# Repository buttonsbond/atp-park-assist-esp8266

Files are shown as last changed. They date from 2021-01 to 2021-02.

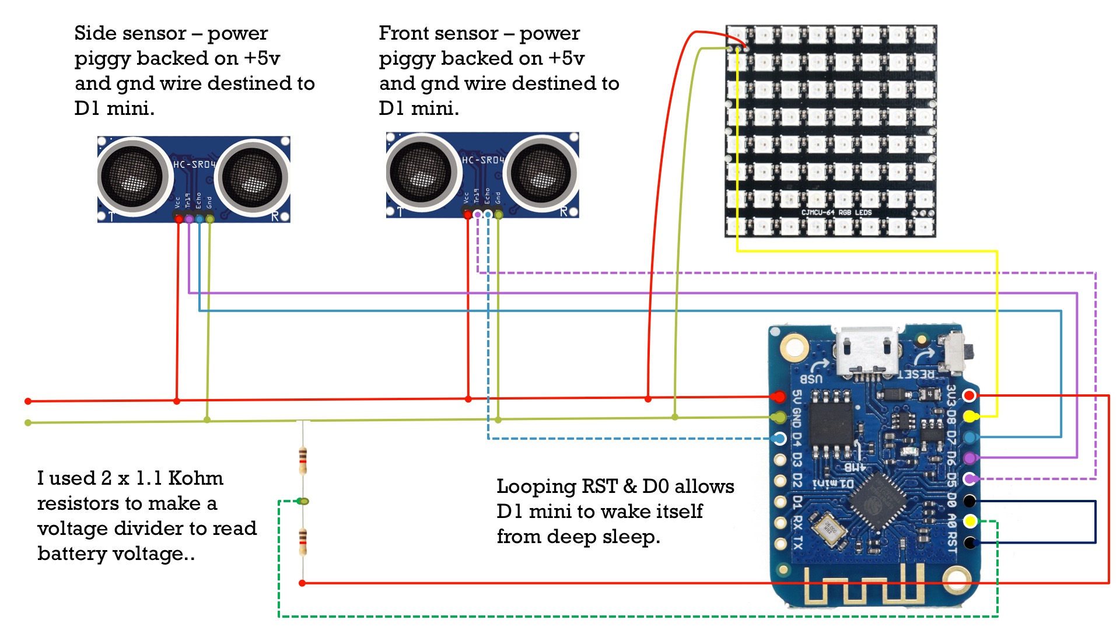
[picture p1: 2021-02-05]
Slide2.jpeg

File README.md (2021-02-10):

# atp-park-assist-esp8266
Parking assist using 2 ultrasonic sensors, 8x8 RGB pixel and d1 mini clone. Optionally you can connect a 4 panel LCD screen to help with debugging/calibrating when the equipment is in situ.
===========================
Just had an automatic rolling door fitted to the drive. Parking is a bit tight due to the car port we have, the middle posts get in the way of the drivers/passenger door opening. It is possible, if you park just right to get in and out of at least one of those doors. A parking sensor to help would be just the job, one to judge if the car is far enough forward, and another at the side to judge if over to the right enough. This project utilises 2 ultrasonic 5v sensors (HC-SR04), a D1 Mini clone (4Mb version), and an 8x8 RGB pixel panel.

most of default settings can be changed in settings.h

Features
========

1. Calibrate either sensor for its minimum distance by placing your fingers over each sensor. A reading of over 1000 will result triggering the calibrate routine.
2. Advancing arrow shown in green, yellow then red (on the 8x8 RGB) for the front sensor. When red, it's time to stop!
3. Left and right hand side of the RGB shown in green, yellow then blue for the side sensor. Blue means your car is far enough over.
4. When no change in forward movement is detected - ie. reading doesn't change much, the micro-controller will enter deepsleep (whether this helps save the battery only time will tell)
5. Various variables saved to RTC when the unit sleeps, and reloaded when it wakes up - a quick front reading is taken and if there still isn't any change the controller enters deepsleep again.
6. OTA updating is possible - it may fail if you happen to try and upload during a sleep operation.
7. An LCD display can be connected to monitor the units operation (recommended only for debugging/setup) - comment out in the code to disable support.
8. Voltage can be monitored if enabled - not fully implemented to do anything with yet but ideally for a low battery warning.
9. MQQT implemented to send front and side readings, f&s limits (after a calibration), time (periodically), whether parked or not (1 or 0), voltage level (see notes further down). 

3D Models
=========
The folder final-models contains some STL files of the enclosures I created and used - the originals are in Tinkercad. 
* remixed-from-tinkercad-user-weselle - in this folder 2 x STL files for the ultrasonic sensor enclosure. Bear in mind that I bent the pins almost fully back on themselves rather than sticking out of the top/bottom - if you still want the pins sticking out the bottom/top then checkout weselle on Tinkercad.
* boxslot.stl - the main box with a thin lip in the bottom to stop the LED grid falling out (you can optionally print insert.stl in white to create a diffuser to go in first ahead of the LED grid.
* mountsall.stl - this is an square 1mm insert that goes in on top of the LED grid, it has posts for mounting D1 mini (my version has holes for the posts to go through), posts for mounting standard DC buck converter, and a holder for 12V 23A battery, the battery found commonly in cheap doorbell push button units.
-- note, that original idea of using a buck converter with a 12V battery wasn't sound - novice that I am, didn't know that the converter would run the battery down even when nothing connected, so plan b is to add a battery shield to the D1 mini and a LIPO battery of 1200mah. I am hoping that with the deep sleep used in the programming that the battery will last a while without recharging. I will expose the usb charging port to allow recharging from something like a power bank.
* plug.stl - this is the mount I made to slot into the metal aluminium tubing I mount the main unit on, it slides into place (quite tightly)
* insert.stl - print this in white PLA for a diffuser (optional) - FILE NOT YET ADDED
* lid.stl - lid for the main box - FILE NOT YET ADDED

You'll need 2 each of the ultrasonic sensor models.

TO DO
=====

1. Low battery warning (see note under wiring up!)
2. Try and further combat spurious readings from the sensors (tried a few libraries) - if anyone can offer a solution that'd be appreciated. I've built in various checks to try and combat this. I read somewhere that the Newping library might be an option which I might try once I've got the power issues sorted.
3. When red, instead of an advancing arrow maybe just flashing red square.

I recommend that once you configure for your car that you hard code those distances in settings.h

Wiring up
=========
I've included a couple of exported Powerpoint slides to show how I wired up. However, it's not quite right - I need some help on this one. Basically I have a small solar panel repurposed from a solar outside light from LIDL - it gives out up to about 5 volts when in direct sun. No idea what the charge current is. It's enough to light the red LED on the battery shield but I don't think it is enough for charging.
I added in the power board so that the battery shield output should give 5 volts for as long as it can (this of course makes my voltage measurement incorrect, and since I haven't put the battery shield in the same enclosure as the D1 mini unless I run a separate wire for the 3v output of the battery shield module to the d1 mini I won't be able to get a reading from the batteries - maybe I don't need the voltage regulator if I can get the solar charging working). The battery drains after about 8 or 9 hours (2000mah 3.7v lion battery) at the moment.
I'm not an electronics expert by any stretch of the imagination so if someone can let me know what the setup should be - comment away!

Libraries needed/used
=====================

Thanks to the respective authors of these libraries, and apologies if I missed any

* https://github.com/bbkbarbar/Arduino-HC-SR04-library
* https://github.com/highno/rtcvars

Caveat
I recommend you use the same pins as I did. I had an issue with one of the (now) unused pins when the LCD panel was also in use in that one of the sensors stopped working. Not sure why but changing it got over that.

Say hi
If you like my project, please send me a photo and say hi. If you have any improvements, be my guest and remember to share back!

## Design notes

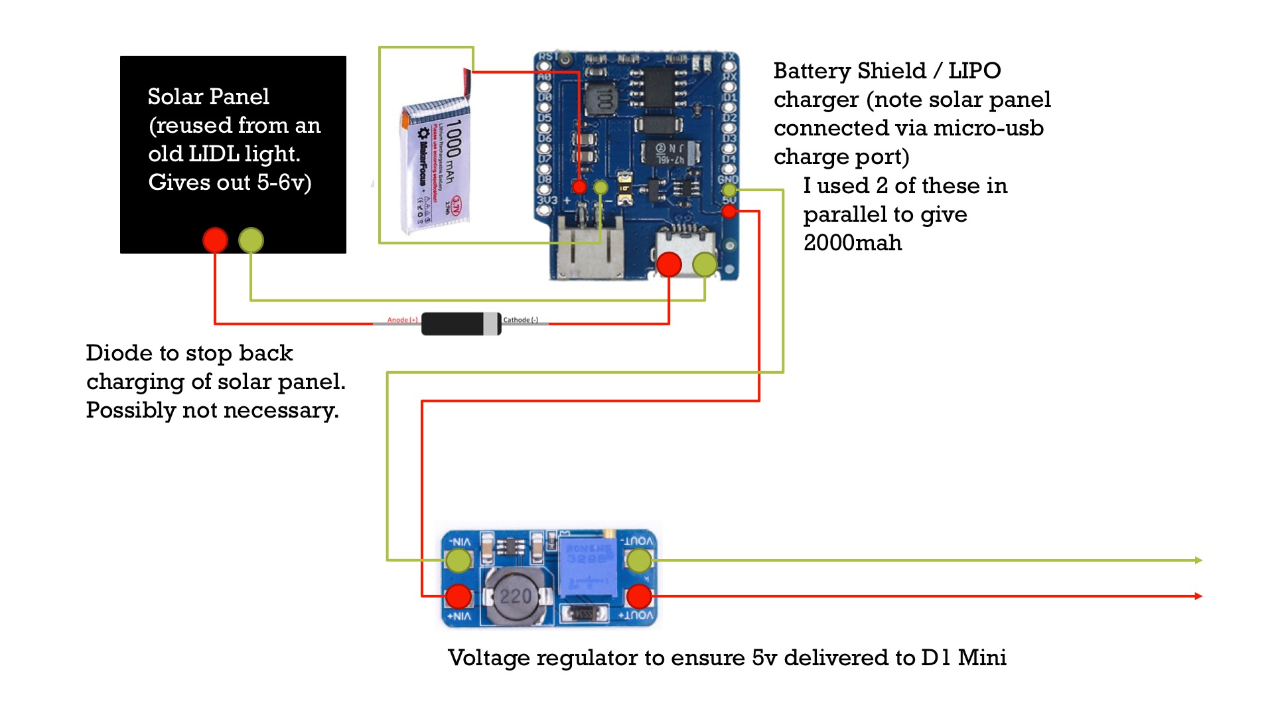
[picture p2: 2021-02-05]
Slide1.jpeg

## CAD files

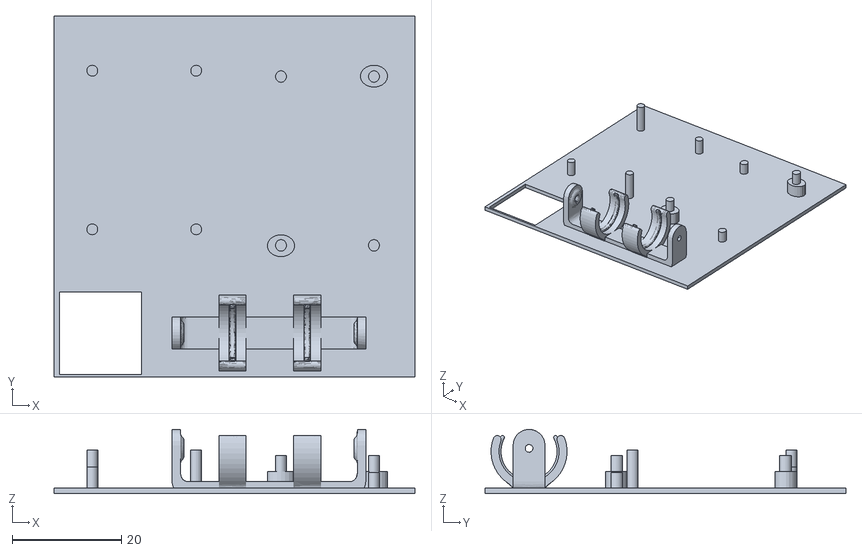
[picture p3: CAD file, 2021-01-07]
final-models/mountsall.stl
66.0 x 66.0 x 11.7

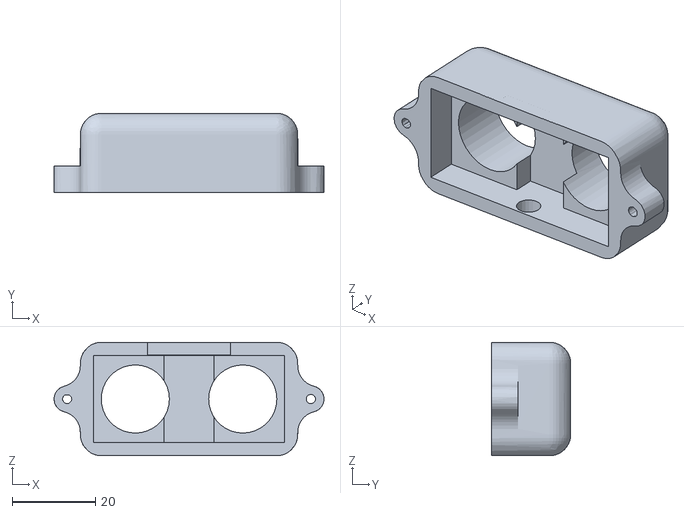
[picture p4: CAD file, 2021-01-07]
final-models/remixed-from-tinkercad-user-weselle/hcsr04case.stl
65.0 x 19.1 x 27.3

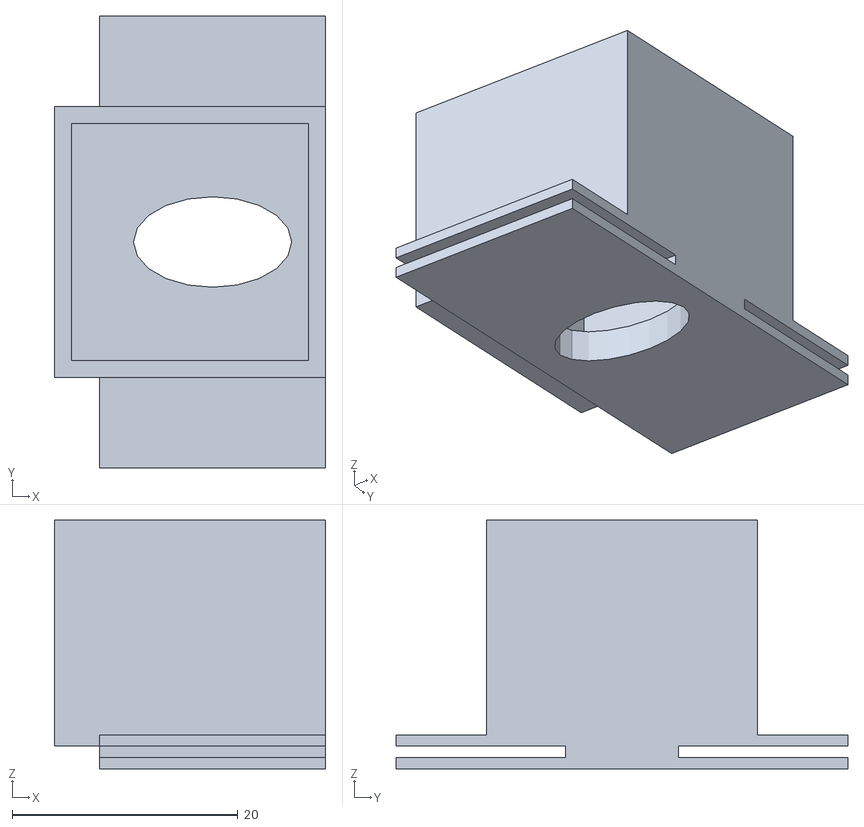
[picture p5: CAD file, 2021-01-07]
final-models/plug.stl
24.0 x 40.0 x 22.0

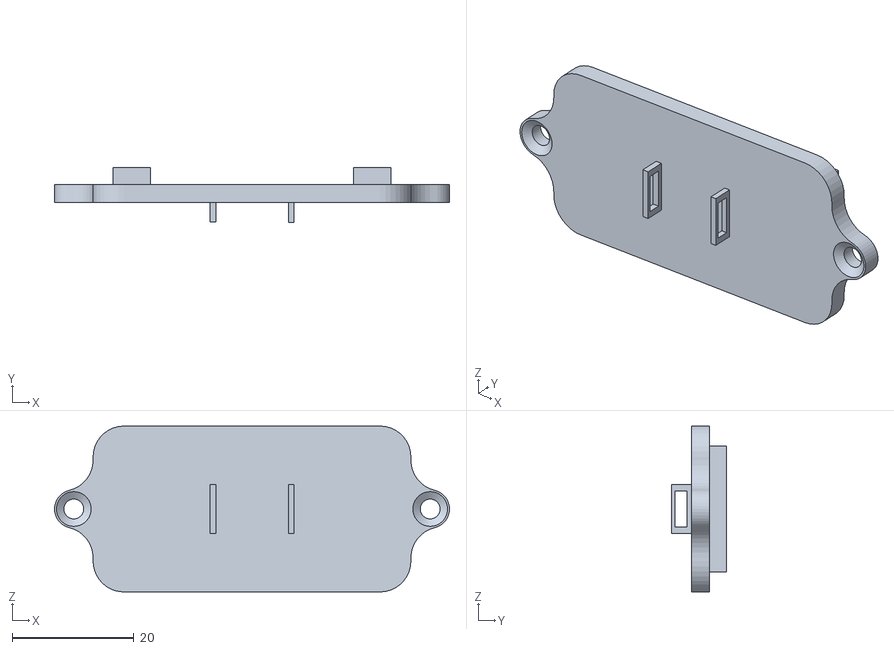
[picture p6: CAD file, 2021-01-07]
final-models/remixed-from-tinkercad-user-weselle/hcsr04lid.stl
65.0 x 9.09 x 27.3

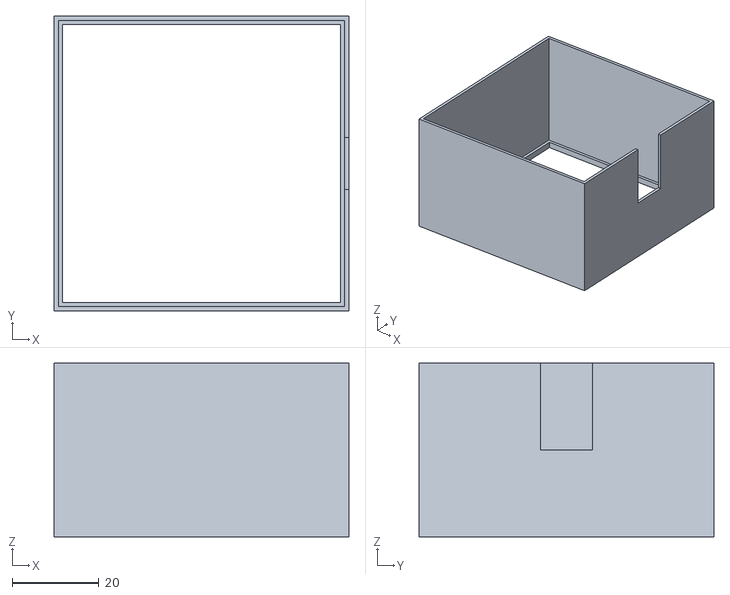
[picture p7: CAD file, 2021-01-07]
final-models/boxslot.stl
68.0 x 68.0 x 40.0

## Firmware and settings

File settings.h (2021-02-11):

struct pcolour {int r; int g; int b;} __attribute__((packed));
typedef struct pcolour PC;
PC rgb;

char* host = "parking";   // Friendly hostname (todo: generate a unique hostname so don't have to set on per board basis
String h = "parking";

// Replace with your network credentials
const char* ssid = "Telfy_3316";
const char* password = "jonesxa1";

// Settings for the HC-SR04 sensors
//
// setup for ultrasonic detector 1 - this will be use to measure distance to front of car
//const int trigPinFront = 
const int trigPinFront = D4; 
const int echoPinFront = D5;
// setup for ultrasonic detector 2 - this will be used to measure distance of side of car to check for correct door opening
const int trigPinSide = D6;
const int echoPinSide = D7;
//
// variables for timings for sound to bounce back and be detected and then to store the distance in
//
long durationFront;
int distanceFront;
long durationSide;
int distanceSide;

// ideally once you know the side and front values for parking your car you should change the values below
// these will then default on power restore
// also measure your distance maxes - front will be from the sensor to your garage door, side will be approx
// the width of your car

int SetDistanceSide = 35; // default distance to passenger door
int SetDistanceFront = 13; // default distance value
int SetDistanceSideMax = 80; // if the distance from the side of the car is more than this, probably no car in the drive!
int SetDistanceFrontMax = 180; // if any more than this then probably no car in drive
int MidFront = (SetDistanceFrontMax - SetDistanceFront) / 2;
int MidSide = (SetDistanceSideMax - SetDistanceSide) / 2;

double dataFront;
double dataSide; 

// D0
//
// apparently if I want to make use of deep sleep, I need to use D0 and RST joined together
// there should be a switch that can be turned on/off on this otherwise you can't do OTA
// or USB upload for that matter.
//
// D1 and D2 (SCL / SDA)
//
// These pins used for LCD panel which I just use for displaying debug messages
//
// comment out if you don't want to send message to an LCD panel.
//#define LCD_DEBUG
// remove comment if you want serial debugging
//#define SERIAL_DEBUG
// comment out if you don't want MQTT reporting
#define ENABLE_MQTT
 #ifdef ENABLE_MQTT
    WiFiClient wClient;
    PubSubClient client(wClient); // was client
  #endif
//
// setup for the FastLED system
//
#define FASTLED_INTERNAL // this disables the pragma messages during compile time
#include <FastLED.h>
FASTLED_USING_NAMESPACE
#define FASTLED_ESP8266_NODEMCU_PIN_ORDER
//define FASTLED_ESP8266_D1_PIN_ORDER
#define DATA_PIN 8   
const int NUM_LEDS = 64; // this is an 8x8 pixel

uint8_t gHue = 100; // rotating "base color" used by many of the patterns

#ifdef LCD_DEBUG
  #define BRIGHTNESS  1 // not sure if this will help with the 5v to power the lcd panel by making LEDs dimm
  int ledbrightness = 1;
#else if
  #define BRIGHTNESS 10
  int ledbrightness = 10;
#endif 
#define FRAMES_PER_SECOND 30

// declare the array of LEDs
CRGB leds[NUM_LEDS];


// OTA updates
#define ENABLE_OTA      // comment out if you don't want OTA updates
int OTAport = 8266;

// monitor battery voltage
// in the circuit I used 2 12k resistors one from the 3.3v rail the other to the ground rail, with a wire
// connecting from middle of those (voltage divider) to the D1 mini A0 analog input
const int VOLTAGE_IN = A0;
double voltage = 0; 

// sleep delays

int StandardSleep = 10; // sleep time when battery ok
double StandardSleepVolt = 3.3; // volts must be higher than this for the shorter sleep period
int LowPowerSleep = 49; // sleep time when battery getting low
int InactiveSleep = 301; // sleep time during inactive hours
int InactiveStart = 1;
int InactiveEnd = 6;
int CurrentSleep = StandardSleep;
int CurrentHour = 12;
int CurrentMin = 0;
char mytime[6] = "12:00";
int successivechecks = 0;

// time settings
const long utcOffsetInSeconds = 3600;

//
// 
int nochange = 0;
int samereading = 0;
int samereadingcounter = 0;
int CalibrateDistance = 1000; // I think the sensor limit is about 4 metres or so  - you might need to fiddle around with this to see what high reading you get when you cover the sensors

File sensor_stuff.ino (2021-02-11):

void GetDistances(void) {
  TestFront();
  topright(); // output for LCD if enabled
  bottomright(); // output for LCD if enabled
  if (nochange==0) {
  TestSide(); // only test side when the whole shebang is up and running - otherwise if its just a wakeup to check, just test the front sensor
  }
}

void TestFront(void) {
  boolean done = false;
  Front();
  FastLED.setBrightness(ledbrightness);
  FastLED.delay(1000/FRAMES_PER_SECOND);

// only do the LEDs if change in reading
if (nochange==0) {
 
 if (distanceFront <= SetDistanceFront) {
    advance('R'); // Side 'STOP'
    debugmessages("FT: STOP  ");
    done = true;
  }
  if ((distanceFront > MidFront) && (!done)) {
    advance('G'); // Front is miles away
    debugmessages("FT: FAR   ");
    done = true;
  }

  if ((distanceFront <= MidFront) && (!done)) {
    advance('Y'); // front is somewhere between half way there and optimal
    debugmessages("FT: NEAR  ");
    done = true;
  }

}

  if ((distanceFront > CalibrateDistance)) {
      // we will check 1 more time after a delay to make sure this really is a calibration request
      debounce('F');
        if (distanceFront > CalibrateDistance) {
            debugmessages("FRONT CALIBRATION");
        calibrateFront('F');
        Front();
        // the value just read needs to be set to the minimum now
        SetDistanceFront=distanceFront;
        if (SetDistanceFront > SetDistanceFrontMax) { SetDistanceFrontMax = SetDistanceFront * 2; } // hopefully stops any minus values
        MidFront = SetDistanceFront + ((SetDistanceFrontMax - SetDistanceFront) / 2); 
        #ifdef SERIAL_DEBUG       
          Serial.print("Front values set to min distance front ");
          Serial.print(SetDistanceFront);
          Serial.print(" and half way to ");
          Serial.println(MidFront);
        #endif
           debugmessages("                  ");
        #ifdef LCD_DEBUG
           lcdmessage(2,"Front min " + String(SetDistanceFront));
           lcdmessage(3,"Front hwy " + String(MidFront));
        #endif       
        lightsoff();
        delay(3000);
        }
  }

 
}

void TestSide(void) {
  boolean done = false;
  Side();
  FastLED.setBrightness(ledbrightness);
  FastLED.delay(1000/FRAMES_PER_SECOND);

  if (distanceSide <= SetDistanceSide) {
    side('B'); // Side 'STOP'
    debugmessages2("SD: STOP  ");
    done = true;
  }
  if ((distanceSide > MidSide) && (!done)) {
    side('G'); // Side is miles away
    debugmessages2("SD: FAR   ");
    done = true;
  }

  if ((distanceSide <= MidSide) && (!done)) {
    side('Y'); // side is somewhere between half way there and optimal
    debugmessages2("SD: NEAR  ");
    done = true;
  }

  if ((distanceSide > CalibrateDistance)) {
      // we will check 1 more time after a delay to make sure this really is a calibration request
      debounce('S');
        if (distanceSide > CalibrateDistance) {
        debugmessages("SIDE CALIBRATION");
        calibrateFront('S');
        Side();
        // the value just read needs to be set to the minimum now
        SetDistanceSide=distanceSide;
        if (SetDistanceSide > SetDistanceSideMax) { SetDistanceSideMax = SetDistanceSide * 2; } // hopefully stops any minus values
        MidSide = SetDistanceSide + ((SetDistanceSideMax - SetDistanceSide) / 2); 
        #ifdef SERIAL_DEBUG   
          Serial.print("Side values set to min distance side ");
          Serial.print(SetDistanceSide);
          Serial.print(" and half way to ");
          Serial.println(MidSide);
        #endif
        debugmessages("                  ");
        #ifdef LCD_DEBUG
           lcdmessage(2,"Side min " + String(SetDistanceSide));
           lcdmessage(3,"Side hwy " + String(MidSide));
        #endif       
        lightsoff();
        delay(3000);
        }
  }
}

void debounce(char frontorside) {
  // was getting a few false readings of out of range which I use to calibrate the sensors so need to
  // take a few readings to make sure it is a calibration request 
  boolean falsereading=true;

  // now the kit is in place, and when the drive is empty seems getting > CalibrateDistance readings so
  // going to force it to make more checks than 8, trying 20
  for (int test=0; test < 20; test++) {
    if (frontorside == 'F') {
      Front();
      //Serial.println(distanceFront);
    } else {
      Side();
      //Serial.println(distanceSide);
    }
    delay(100);
    if (frontorside == 'F')
        {
        if (distanceFront < CalibrateDistance) {
          test=20;
          falsereading=true;
          } else {
          falsereading=false;
          }
        } else
        {
        if (distanceSide < CalibrateDistance) {
          test=20;
          falsereading=true;
          } else {
          falsereading=false;
          }
        }
  if (frontorside == 'F') {
    // this part of the code will hike the measured reading if it has found that it seems to be a calibration request
    // it was +200, changing to multiply x 2
    if (!falsereading) { distanceFront=CalibrateDistance*2; } else { distanceFront=samereading; }
  } else {
    if (!falsereading) { distanceSide=CalibrateDistance*2; } else { distanceSide=samereading; }    
  }
}
}
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

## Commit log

2020-11-16 updated
    using a library for the HCSR04 which has a bit more to it - source of library is https://github.com/bbkbarbar/Arduino-HC-SR04-library
2020-11-17 a good working version
    Code needs tidying up a bit, and perhaps could do with some more comments. I'll do that for the next release once I've 3d printed some enclosures and put the project in place.
2021-01-07 added some of the STL files for 3d printing
    still a couple of parts to come
    [boxslot.stl, hcsr04case.stl, hcsr04lid.stl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]
2021-02-05 wiring diagrams version 1
    this is how i've got mine wired - I've recently added the voltage regulator as the d1 mini was flaking out if the panel got too much sunlight - at least that's what I put it down to.
